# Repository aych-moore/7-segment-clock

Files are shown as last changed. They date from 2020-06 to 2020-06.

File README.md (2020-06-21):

# 7-segment-clock

## 3D printing

The clock is modular. In order to create a 4 digit clock I printed:

I designed all of the following components in Fusion 360

* 1x clock-body-center-connector.stl
* 4x clock-body-digit.stl
* 2x clock-body-digit-connector.stl
* 2x clock-body-end.stl

Settings I used:

* 1.75mm PLA brass filament
* 0.2mm layer height
* 8 perimeter brim
* 5% gyroid infill
* 205 celcius nozzel
* 60 celcius bed

Print time was about 60-70 hours. 

After printing I heat set m3 threadded inserts into the plastic so it could be screwed to the base plate.

## Laser cutting

### Backplate

The baseplate was laser cut from 3mm ply wood. There are holes for zip ties for cable management and holes for m3 bolts to attach the base plate to the 3D printed clock body.

I cut one piece:

* baseplate.svg

### Diffusers

The diffusers are placed above the LEDs and make the light softer and more even. I used 3mm clear acrylic and etched lines in it to make it very textued. The red lines are cut lines and the blue lines are etch lines that are etched at twice the speed of the cut lines so they don't go all the way through. I think opal acrylic without the etch lines would have also looked very nice.

I cut these pices:

* 4x digit-diffuser.svg
* 2x circle-diffuser.svg

## Electronics

A WS2812B 144led/m strip was cut into lengths of 9 LEDs and stuck to the baseplate within the etch lines. Two lengths that are 2 LEDs long are also cut.

Stripped solid core wire is soldered to the strips to connect them in a snake pattern.

An ESP32 is placed in the center to control the LED strips.

## Programming

Code is uploaded to the ESP32 to control the LEDs.

## Todo

* Step up data signal to 5V with level shifter
* Laser cut diffusers
* 1000uF capacitor on each strip
* ESP32 web server to change colours and run functions
* Add photo of clock and CAD files

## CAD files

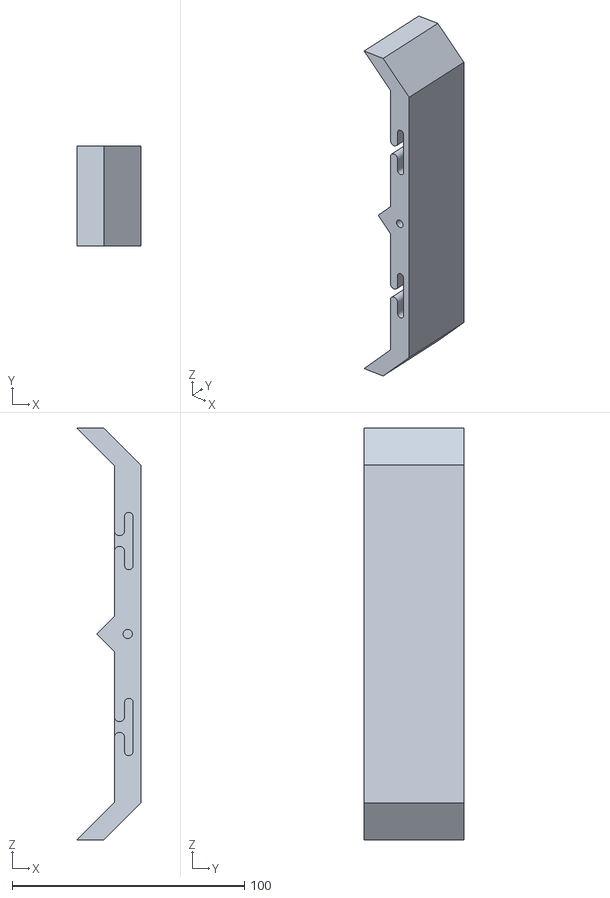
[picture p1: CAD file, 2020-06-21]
stl-files/clock-body-end.stl
27.7 x 43.0 x 177.3

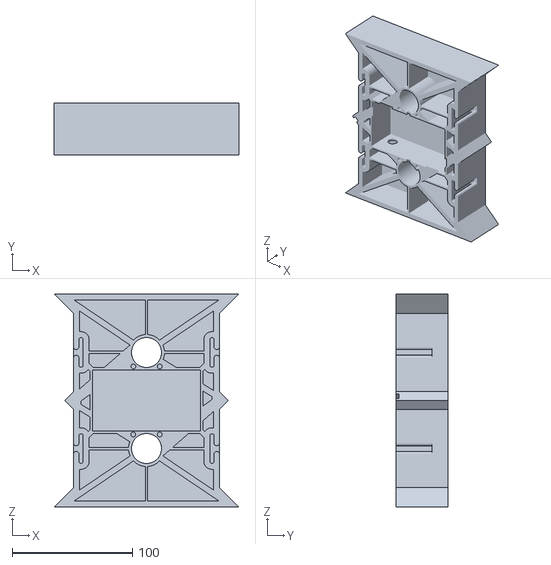
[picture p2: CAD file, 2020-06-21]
stl-files/clock-body-center-connector.stl
153.7 x 43.0 x 177.3

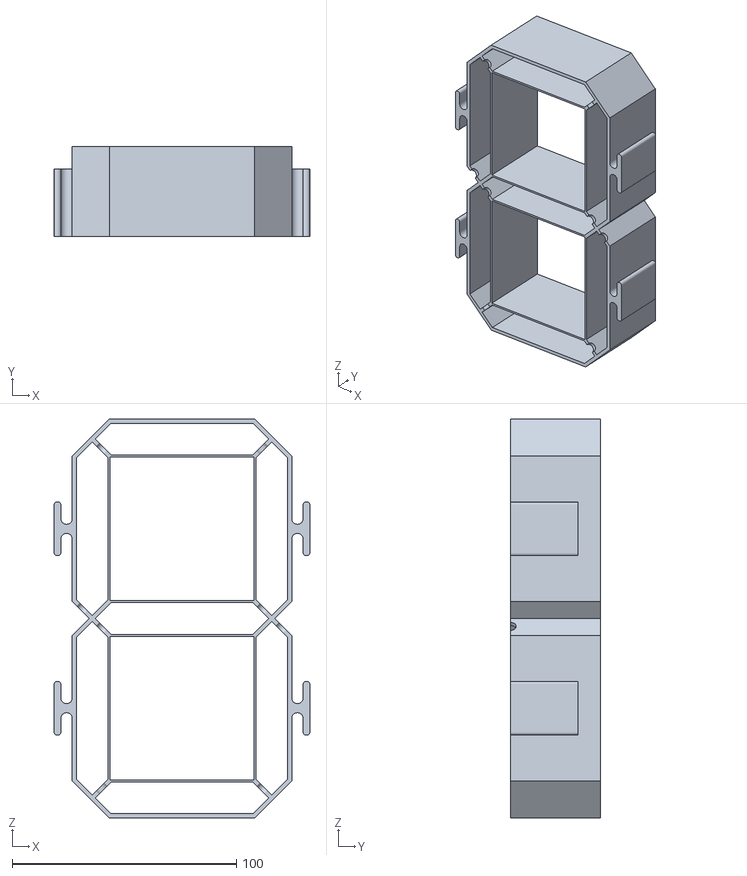
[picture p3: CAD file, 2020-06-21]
stl-files/clock-body-digit.stl
114.0 x 40.0 x 177.9

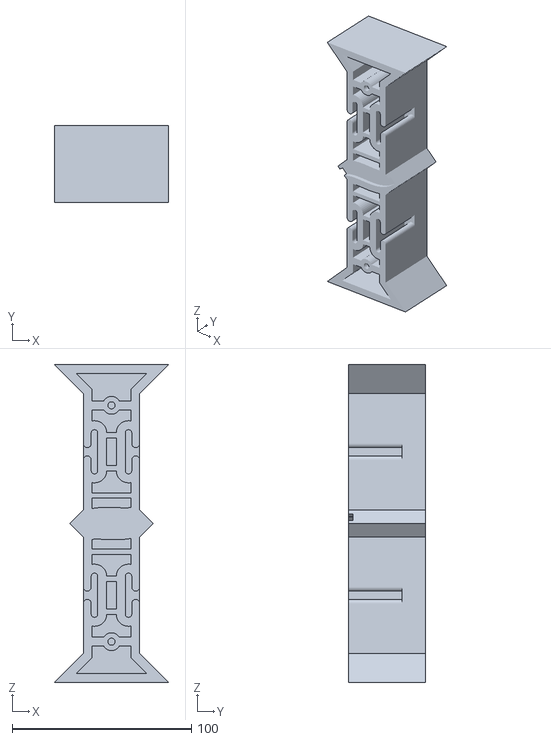
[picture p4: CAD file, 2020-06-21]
stl-files/clock-body-digit-connector.stl
63.8 x 43.0 x 177.3

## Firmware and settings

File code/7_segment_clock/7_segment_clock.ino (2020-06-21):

#include <FastLED.h>
#include <WiFi.h>
#include "time.h"

#define NUM_LEDS 128
#define DATA_PIN_LEFT 19
#define DATA_PIN_RIGHT 32

const char* ssid       = "2=={::::::::::>";
const char* password   = "7NBMXRTKEP";

const char* ntpServer = "pool.ntp.org";
const long  gmtOffset_sec = 43200;
const int   daylightOffset_sec = 0; //3600

byte hour;
byte minute;

bool separatorsOn = false;

CRGB ledsLeft[NUM_LEDS];
CRGB ledsRight[NUM_LEDS];

/*

         A
        ----
      F \    \ B
         \____\
        E \ G  \ C
           \____\
              D

HOUR
DOT 0,1
B 2,10
A 11,19
F 20,28 
G 29,37
C 38,46
D 47,55
E 56,64
B 65,73
A 74,82
F 83,91
G 92,100
C 101,109
D 110,118
E 119,127

MINUTE
DOT 0,1
E 2,10
D 11,19
C 20,28 
G 29,37
F 38,46
A 47,55
B 56,64
E 65,73
D 74,82
C 83,91
G 92,100
F 101,109
A 110,118
B 119,127

0 ABCDEF
1 BC
2 ABDEG
3 ABCDG
4 BCFG
5 ACDFG
6 CDEFG
7 ABC
8 ABCDEFG
9 ABCFG


 */     
//                                                           INDEX SEGMENT MAPPINGS                       
//                                            INSIDE                   |                 OUTSIDE
//                  HOUR   DOT  B    A     F     G      C     D     E     B     A     F     G      C       D       E             
//                  MINUTE DOT  E    D     C     G      F     A     B     E     D     C     G      F       A       B
//                         0 1 2 3  4  5  6  7  8  9  10 11 12 13 14 15 16 17 18 19 20 21 22 23  24  25  26  27  28  29
//start and end index     {0,1,2,10,11,19,20,28,29,37,38,46,47,55,56,64,65,73,74,82,83,91,92,100,101,109,110,118,119,127};

//==================================== LED INDEX MAPPINGS FOR SEGMENTS ====================================

//                                   A    B    C    D    E    F    G 
const byte hourTensDigits[10][7] = {{74,  65,  101, 110, 119, 83,  0},  //0
                                    {0,   65,  101, 0,   0,   0,   0},  //1
                                    {74,  65,  0,   110, 119, 0,   92}, //2
                                    {74,  65,  101, 110, 0,   0,   92}, //3
                                    {0,   65,  101, 0,   0,   83,  92}, //4
                                    {74,  0,   101, 110, 0,   83,  92}, //5
                                    {0,   0,   101, 110, 119, 83,  92}, //6
                                    {74,  65,  101, 0,   0,   0,   0},  //7
                                    {74,  65,  101, 110, 119, 83,  92}, //8
                                    {74,  65,  101, 0,   0,   83,  92}};//9
                                    
//                                   A    B    C    D    E    F    G 
const byte hourOnesDigits[10][7] = {{11,  2,   38,  47,  56,  20,  0},  //0
                                    {0,   2,   38,  0,   0,   0,   0},  //1
                                    {11,  2,   0,   47,  56,  0,   29}, //2
                                    {11,  2,   38,  47,  0,   0,   29}, //3
                                    {0,   2,   38,  0,   0,   20,  29}, //4
                                    {11,  0,   38,  47,  0,   20,  29}, //5
                                    {0,   0,   38,  47,  56,  20,  29}, //6
                                    {11,  2,   38,  0,   0,   0,   0},  //7
                                    {11,  2,   38,  47,  56,  20,  29}, //8
                                    {11,  2,   38,  0,   0,   20,  29}};//9

//                                     A    B    C    D    E    F    G 
const byte minuteTensDigits[10][7] = {{47,  56,  20,  11,  2,   38,  0},  //0
                                      {0,   56,  20,  0,   0,   0,   0},  //1
                                      {47,  56,  0,   11,  2,   0,   29}, //2
                                      {47,  56,  20,  11,  0,   0,   29}, //3
                                      {0,   56,  20,  0,   0,   38,  29}, //4
                                      {47,  0,   20,  11,  0,   38,  29}, //5
                                      {0,   0,   20,  11,  2,   38,  29}, //6
                                      {47,  56,  20,  0,   0,   0,   0},  //7
                                      {47,  56,  20,  11,  2,   38,  29}, //8
                                      {47,  56,  20,  0,   0,   38,  29}};//9

//                                     A    B    C    D    E    F    G 
const byte minuteOnesDigits[10][7] = {{110, 119, 83,  74,  65,  101, 0},  //0
                                      {0,   119, 83,  0,   0,   0,   0},  //1
                                      {110, 119, 0,   74,  65,  0,   92}, //2
                                      {110, 119, 83,  74,  0,   0,   92}, //3
                                      {0,   119, 83,  0,   0,   101, 92}, //4
                                      {110, 0,   83,  74,  0,   101, 92}, //5
                                      {0,   0,   83,  74,  65,  101, 92}, //6
                                      {110, 119, 83,  0,   0,   0,   0},  //7
                                      {110, 119, 83,  74,  65,  101, 92}, //8
                                      {110, 119, 83,  0,   0,   101, 92}};//9

                        

void displayDigit(byte digitIndex, byte numberToDisplay){
  switch(digitIndex){
    case 0: //hourTens
      for(byte i = 0; i < 7; i++){
        if(hourTensDigits[numberToDisplay][i] != 0){
          for(byte j = hourTensDigits[numberToDisplay][i]; j < hourTensDigits[numberToDisplay][i]+9; j++){
            ledsLeft[j] = CRGB(254, 40, 3); //254, 72, 3
          }
        }
      }
      break;
    case 1: //hourOnes
      for(byte i = 0; i < 7; i++){
        if(hourOnesDigits[numberToDisplay][i] != 0){
          for(byte j = hourOnesDigits[numberToDisplay][i]; j < hourOnesDigits[numberToDisplay][i]+9; j++){
            ledsLeft[j] = CRGB(254, 40, 3);
          }
        }
      }
      break;
    case 2: //minuteTens
      for(byte i = 0; i < 7; i++){
        if(minuteTensDigits[numberToDisplay][i] != 0){
          for(byte j = minuteTensDigits[numberToDisplay][i]; j < minuteTensDigits[numberToDisplay][i]+9; j++){
            ledsRight[j] = CRGB(254, 40, 3);
          }
        }
      }
      break;
    case 3: //minuteOnes
      for(byte i = 0; i < 7; i++){
        if(minuteOnesDigits[numberToDisplay][i] != 0){
          for(byte j = minuteOnesDigits[numberToDisplay][i]; j < minuteOnesDigits[numberToDisplay][i]+9; j++){
            ledsRight[j] = CRGB(254, 40, 3);
          }
        }
      }
      break;
  }
}


void printLocalTime()
{
  struct tm timeinfo;
  if(!getLocalTime(&timeinfo)){
    Serial.println("Failed to obtain time");
    return;
  }
  Serial.println(&timeinfo, "%A, %B %d %Y %H:%M:%S");
  hour = timeinfo.tm_hour;
  minute = timeinfo.tm_min;

  //convert to 12 hour
  if(hour > 12){
    hour -= 12;
  }

  
  

  byte hourOnes = (hour%10); //change to hour
  byte hourTens = ((hour/10)%10); //change to hour
  byte minuteOnes = (minute%10);
  byte minuteTens = ((minute/10)%10);

  clearAllDigits();
  
  if(hour >= 10){ //remove leading 0 for hour
    displayDigit(0,hourTens);
  }
  displayDigit(1,hourOnes);
  displayDigit(2,minuteTens);
  displayDigit(3,minuteOnes);
  FastLED.show();

  
}

void toggleSeparators(){
  if(separatorsOn){ //if on then turn off
    for(int i = 0; i < 2; i++){
      ledsLeft[i] = CRGB(0,0,0);
      ledsRight[i] = CRGB(0,0,0);
    }
  }
  else{ //if off then turn on
    for(int i = 0; i < 2; i++){
      ledsLeft[i] = CRGB(254, 40, 3);
      ledsRight[i] = CRGB(254, 40, 3);
    }
  }
  FastLED.show();
}

void clearAllDigits(){
  for(int i = 2; i < NUM_LEDS; i++){
    ledsLeft[i] = CRGB(0,0,0);
    ledsRight[i] = CRGB(0,0,0);
  }
}

void setup() { 
  FastLED.addLeds<NEOPIXEL, DATA_PIN_LEFT>(ledsLeft, NUM_LEDS);
  FastLED.addLeds<NEOPIXEL, DATA_PIN_RIGHT>(ledsRight, NUM_LEDS);

  FastLED.setMaxPowerInVoltsAndMilliamps(5,200); 
  FastLED.clear();

  Serial.begin(115200);
  
  //connect to WiFi
  Serial.printf("Connecting to %s ", ssid);
  WiFi.begin(ssid, password);
  while (WiFi.status() != WL_CONNECTED) {
      delay(500);
      Serial.print(".");
  }
  Serial.println(" CONNECTED");

  //init and get the time
  configTime(gmtOffset_sec, daylightOffset_sec, ntpServer);
  printLocalTime();

  //disconnect WiFi as it's no longer needed
  WiFi.disconnect(true);
  WiFi.mode(WIFI_OFF);

  toggleSeparators(); //off initially so this will turn them on
}
 
void loop() { 
  /*
  for(int i = 0; i < NUM_LEDS; i++){
    ledsLeft[i] = CHSV(255,255,255); 
    ledsRight[i] = CHSV(175,255,255); 
    FastLED.show();
    delay(1); 
    FastLED.clear();
  }
  */
  
  printLocalTime();
  delay(60000);

  /*
  for(byte i = 0; i < 10; i++){
    clearAllDigits();
    displayDigit(0,i);
    displayDigit(1,i);
    displayDigit(2,i);
    displayDigit(3,i);
    FastLED.show();
    delay(1000);
  }
  */
  
}
